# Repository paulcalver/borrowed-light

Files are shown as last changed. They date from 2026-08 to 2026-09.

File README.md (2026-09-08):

# Borrowed Light

*Global Colour: a live network reading the colour of daylight around the world.*

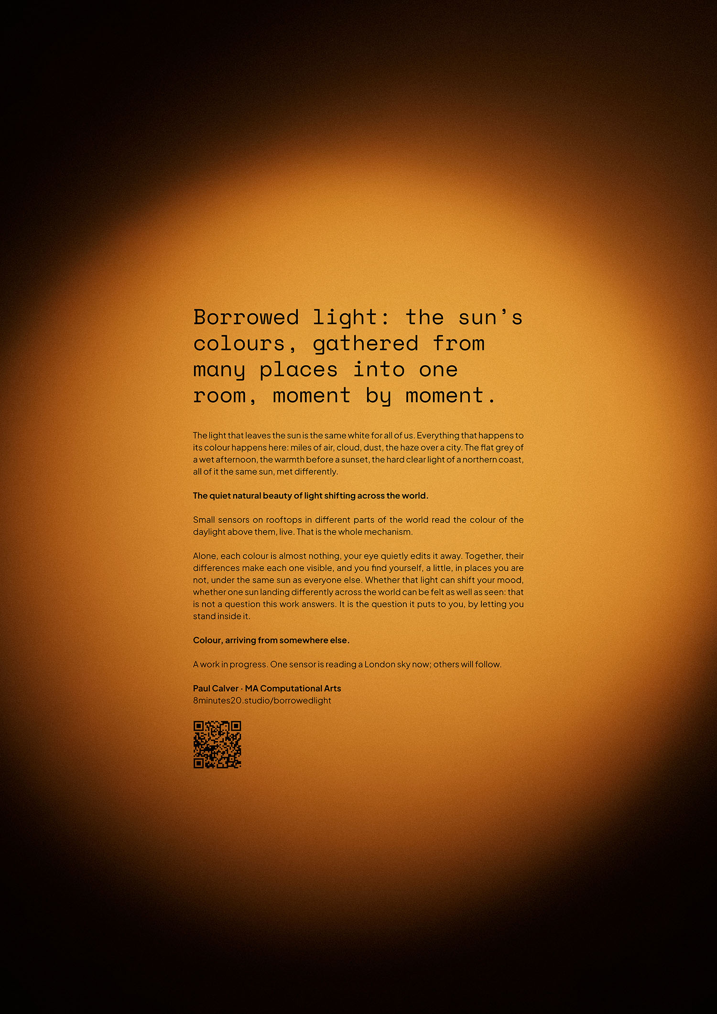
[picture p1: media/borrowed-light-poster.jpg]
Borrowed Light — the sun's colours, gathered from many places into one room, moment by moment. Small sensors on rooftops in different parts of the world read the colour of the daylight above them.


**Borrowed light: the sun's colours, gathered from many places into one room, moment by moment.**

The light that leaves the sun is the same white for all of us. Everything that happens to its colour happens here: miles of air, cloud, dust, the haze over a city. The flat grey of a wet afternoon, the warmth before a sunset, the hard clear light of a northern coast, all of it the same sun, met differently.

*The quiet natural beauty of light shifting across the world.*

Small sensors on rooftops in different parts of the world read the colour of the daylight above them, live. That is the whole mechanism.

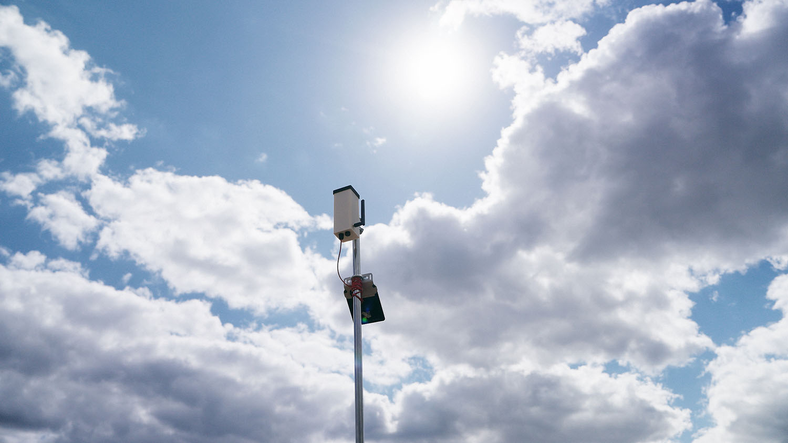
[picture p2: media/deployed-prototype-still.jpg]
A sensor unit mounted at the top of a pole, seen from below against bright sky — the enclosure with its dome facing up, solar panel angled beneath it, sun and cumulus cloud behind.


*A prototype unit in place, dome to the sky.*

Alone, each colour is almost nothing, your eye quietly edits it away. Together, their differences make each one visible, and you find yourself, a little, in places you are not, under the same sun as everyone else. Whether that light can shift your mood, whether one sun landing differently across the world can be felt as well as seen: that is not a question this work answers. It is the question it puts to you, by letting you stand inside it.

*Colour, arriving from somewhere else.*

A work in progress, and openly so. One sensor has been reading a London sky; others will follow, elsewhere. What form the standing-inside finally takes, whether light, projection, or something else, is still being explored.

**[8minutes20.studio/borrowedlight](https://8minutes20.studio/borrowedlight)**

If you would like to hear more about the project's plans and ambitions, please do get in touch.

---

## In plain terms

Hold an identical piece of white paper under the sun in different places and it looks a subtly different colour, not because the paper changes, but because the light falling on it does. The eye compensates for this automatically and mostly hides it; the sensor does not, and records the daylight's actual colour instead. The long-term aim is a distributed network of these sensors, one per site (London first, then elsewhere), each feeding the same live dashboard, so that difference becomes something you can see and compare directly.

## Status

Three units exist. `sensor-00` is the bench reference: it stays indoors permanently and is never deployed, so every future unit can be checked against it rather than against a borrowed meter each time. `sensor-01` is the London unit. `sensor-02` will go somewhere else once there is a site for it.

**None of them is in a final position yet.** The units are being rebuilt around new optics, described below, and are running on the bench while that happens. Siting, and a full recalibration once the new stack is fixed, both come after. The photographs here show prototypes in place, not the finished network.

### The dome problem, and its fix

Field readings through the summer of 2026 showed a colour-temperature error that tracked ambient UV rather than the light being measured: on the first outdoor comparison against a reference meter, all three units read between 900K and 1,160K too high, consistently, within seconds of each other. Duv barely moved, which is the signature of added blue light rather than a mis-aimed sensor or a bad fit.

The cause was optical brighteners fluorescing under sunlight — the material absorbs ultraviolet and re-emits it as visible blue, straight into the sensor. A 365nm test in August 2026 confirmed the source: the dome glowed strongly, the printed mixing tube behind it only slightly. Studio calibration had been structurally blind to this, because the lamp used for it emits almost no UV. The error only ever appeared in real sun.

It could not be fitted out afterwards, for reasons covered under [Calibration: physical](#calibration-physical) below. The fix had to be a material change, and that is now resolved. **LIT Systems**, who make the Lit Duo 1 spectrometer, supplied dome diffusers, UV/IR cutoff filters and black foam mounting rings from their own instrument — known-good parts from a working commercial colour meter rather than another material of unknown provenance. All of them pass the 365nm test. Domes were chosen over the flat diffusers deliberately, to keep the warmth of low sun in the readings rather than have it cosine-weighted away.

The enclosure has been reworked around them, and the printed mixing chamber is gone entirely: the foam ring mounts the filter directly over the OPT4048 and the dome sits close above it, so the light path is dome, filter, sensor, with no white plastic in it anywhere. That second change is not only about fluorescence — white ASA yellows over time, a slow, invisible spectral drift that would quietly invalidate any calibration fit. The files in [`mechanical/`](mechanical/) are this revision.

## Technical notes

Adafruit QT Py ESP32-S2, OPT4048 tristimulus colour sensor, Voltaic P126 solar panel (6V, 2W), 2000 mAh LiPo battery, BQ24074 charge controller, MQTT over Wi-Fi, custom 3D-printed enclosure. On-device loop: read CIE x,y chromaticity and lux, publish over MQTT. Server: convert to kelvin, render true colour from the raw measurement. Each unit is designed and hand-built, running on solar power alone with no mains connection. The sensor measures the light itself, not the sky's appearance.

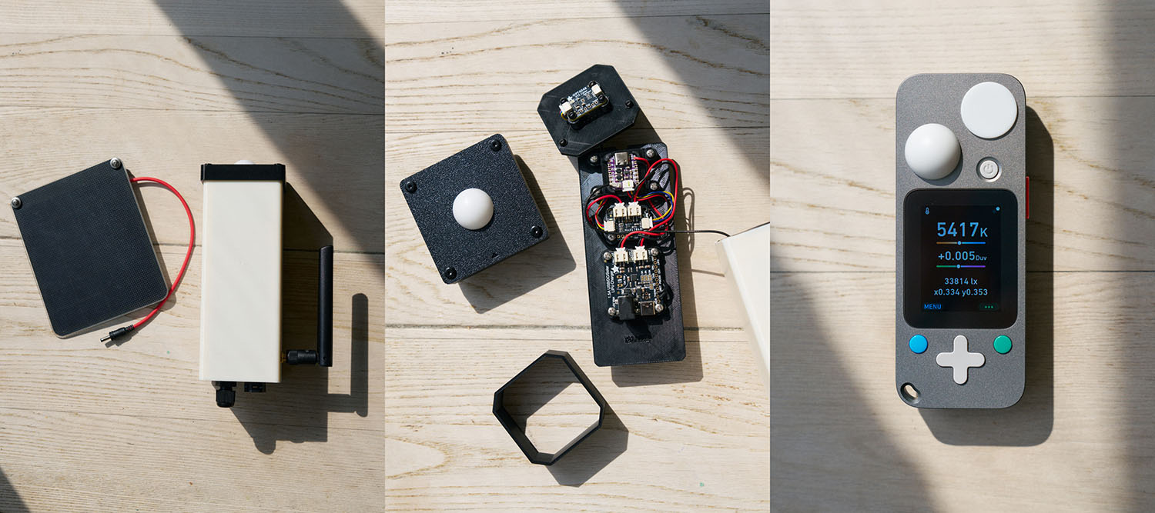
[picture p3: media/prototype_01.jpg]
Three views of a sensor unit: the assembled enclosure beside its solar panel, the same unit opened out to show the dome, the stacked boards and the battery sled, and the handheld reference colour meter reading 5417K at +0.005 Duv.


*Left: an assembled unit with its solar panel. Centre: the same unit opened out — dome and clamp ring, sensor deck, and the sled carrying the microcontroller, fuel gauge and charge controller. Right: the reference colour meter the units are calibrated against. This is the earlier flanged-dome build; the clamp ring and mixing tube are gone in the current revision.*

The rest of this page is the long version of that summary.

---

## How it works

Sensor to `hex`: what each reading goes through, and how separate units are checked against each other and against a physical reference.

### Sensor

An `OPT4048` tristimulus colour sensor sits behind the dome and diffuser, reading four raw channels (`X`, `Y`, `Z`, and a clear `W` channel) once per publish cycle. Unlike an RGB camera sensor, these four channels are built to match the CIE 1931 colour-matching functions directly, so colour and level convert straight to standard colorimetric quantities, CIE `x, y` chromaticity and lux, without a lookup table in between.

### On the device

The microcontroller reads the sensor, takes its `x, y` chromaticity, and derives correlated colour temperature (CCT): the temperature of the blackbody radiator whose colour is the nearest match on the CIE diagram. `cct`, `lux`, `cie_x`, `cie_y`, the raw channel counts, a sensor-overload flag, and battery state are packaged as JSON and published over MQTT to a self-hosted broker.

### On the server

CCT alone collapses a two-dimensional colour to a single number along the blackbody curve, discarding the axis perpendicular to it: whether the light sits slightly green or slightly magenta of a true blackbody at that temperature. The server recovers that as **Duv**, computed from the stored `x, y` using the CIE 1960 UCS transform and a closed-form fit to the Planckian locus (Ohno, 2011), accurate to a few parts in 10⁻⁴ across the daylight range. Each reading is also stamped with the sensor's registered location and the sun's elevation and azimuth at that instant, so a colour can be read against time of day and season, not just in isolation.

### Colour you see

The colour on the grid and full-screen views is the sensor's measured chromaticity rendered as true colour, not a Kelvin-to-RGB approximation. `x, y` is converted to CIE XYZ at unit luminance, then to linear sRGB with the standard D65 primary matrix. Out-of-gamut negative values are clipped, and the result is normalised so the brightest channel reads full strength, brightness being deliberately discarded here, so the display is a pure colour comparison rather than an exposure match. sRGB gamma is applied and the three channels are rounded to 8 bits, giving the `hex` value.

### Calibration: computational

The correction is built, but no sensor has been fitted yet, so every CCT, `x, y`, and Duv value shown is still the sensor's raw reading. It is a small per-unit affine adjustment in mireds (10⁶/K, the scale colour-temperature error behaves linearly on) and Duv, fitted once against a trusted physical reference and then applied at ingest, the same stage Duv is already computed at. Raw values are never overwritten: the calibrated columns sit alongside them and stay empty until a fit exists, so a fit can be refined or redone as more reference data comes in without losing anything.

### Calibration: physical

That reference comes from a direct bench comparison. Two identically built units, same dome, diffuser, and sensor, are run side by side against a borrowed professional colour meter before either goes outdoors. Once the fit is established:

- one unit deploys to its site,
- the other stays permanently on the bench as a fixed source of truth, and
- every future unit gets checked against that bench reference, rather than against the meter each time.

The reference unit is never itself installed outdoors, so its own drift stays out of the loop.

This is also the limit the dome problem ran into. An affine fit can absorb a bias that is stable, or one that varies with colour temperature itself, because both are recoverable from the reading. It cannot absorb one driven by ambient UV, which varies independently of the colour being measured, and that is why the fix had to be a material change rather than a better fit.

---

## This repository

    firmware/     CircuitPython for the QT Py ESP32-S2. Reads the OPT4048,
                  derives CCT on-device, publishes over MQTT. Multi-SSID
                  fallback, NTP-aligned capture, optional OTA pull.
    mechanical/   STEP exports of the IP65 enclosure and its pole and
                  wall-mount brackets, built around the LIT Systems dome.
                  Generated from a parametric model, so geometry is derived
                  rather than drawn: change a component and the box follows.
    server/       Ingests MQTT, computes Duv and solar position, stores
                  readings, and serves the true-colour views.

Host addresses in `firmware/qt-py/settings.toml.example` are placeholders. Set `MQTT_BROKER`, `MQTT_USERNAME`, `MQTT_PASSWORD` and, if you want over-the-air updates, `OTA_BASE_URL` for your own deployment.

A full build guide — bill of materials, wiring, assembly, print settings — is still to come.

## Contact

**Paul Calver** — [paulcalver@me.com](mailto:paulcalver@me.com)

Project page: [8minutes20.studio/borrowedlight](https://8minutes20.studio/borrowedlight)

Do get in touch about putting a sensor on a roof somewhere the network does not
yet reach, or about the project generally.

## Licence

MIT, see [LICENSE](LICENSE). The CircuitPython libraries under `firmware/qt-py/lib/` are redistributed from the Adafruit bundle and keep their own MIT copyright.

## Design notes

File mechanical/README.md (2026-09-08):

# Enclosure

STEP exports of the IP65 sensor enclosure, in millimetres. These are the
published geometry: the parts are generated from a parametric CadQuery model,
and what is exported here is what gets printed.

This is the current revision, built around the LIT Systems dome diffuser — the
UV-stable, brightener-free optic that replaced the earlier fluorescing dome. It
supersedes the flanged-dome enclosure the first prototypes used.

    assembly/
      column_assembly.step    The whole unit as it goes together, including
                              reference bodies for the dome, filter, foam ring,
                              boards and battery — for context and fit-checking,
                              not for printing.

    components/
      box.step                Open-top cup, 66 mm square, 171 mm deep. PG7
                              gland and breather vent in the bottom face;
                              moulded ledges carry the sensor deck, guide
                              fences locate the sled.
      lid.step                Screw-down lid, and the optical head. The dome
                              presses into a 20.5 mm port bore from outside and
                              beds in neutral-cure silicone; a rotation lock
                              catches one of the dome's barrel slots. Everything
                              optical stays with the lid when it lifts off.
      sensor_deck.step        Sits on the box's wall ledges and carries a riser
                              that lifts the OPT4048 up to meet the dome, die up
                              on the dome axis. Riser height is the tuning knob
                              for foam compression — reprint the deck alone to
                              adjust it.
      sled.step               Carries the QT Py, fuel gauge and charge
                              controller, and slides out of the box as one
                              piece.
      battery_cradle.step     Holds the 2000 mAh LiPo against the sled.
      pole_bracket.step       Friction clamp for a pole, dovetailed to the box.
      wall_mount_bracket.step Screws to a flat surface, same dovetail.

## Orientation

TOP is the end carrying the dome port and the screw-down lid; deployed, it faces
the sky. BOTTOM carries the gland and vent and points down, so water drains away
from both.

## Printing

Printed in ASA for UV stability, lid exterior-face down. No white plastic
anywhere in the light path: white ASA yellows over time, which would quietly
drift a calibration fit out from under you.

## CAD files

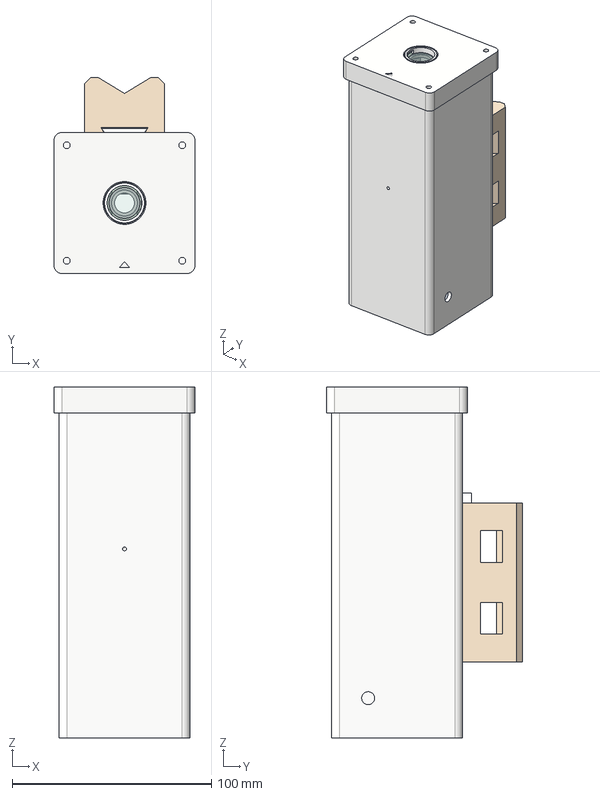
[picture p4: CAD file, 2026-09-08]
mechanical/assembly/column_assembly.step
70.8 x 98.4 x 176.3 mm
box_part
lid_part
deck_part
sled_part
battery_cradle_part
bracket_part
dome_part
ref_uv_ir_filter_part
ref_foam_ring_part
refs_boards_battery_part
ref_opt4048_part

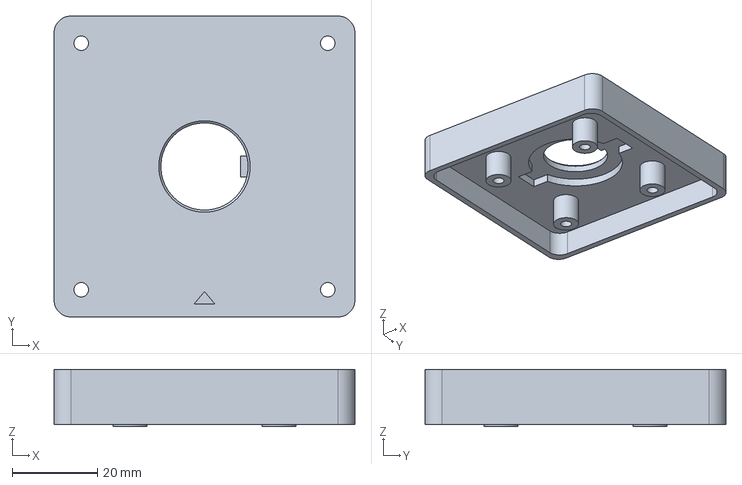
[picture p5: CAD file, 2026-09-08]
mechanical/components/lid.step
70.8 x 70.8 x 13.5 mm

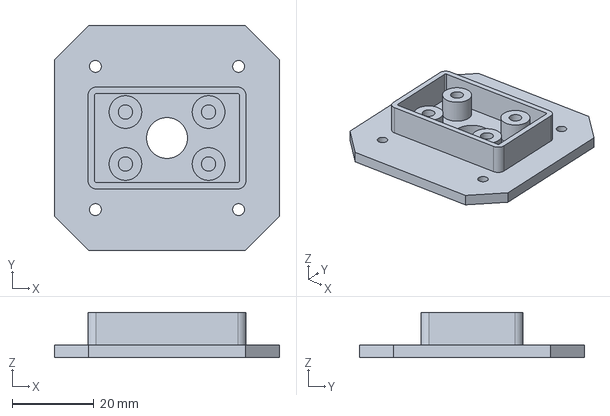
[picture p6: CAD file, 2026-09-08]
mechanical/components/sensor_deck.step
55.0 x 55.0 x 11.0 mm

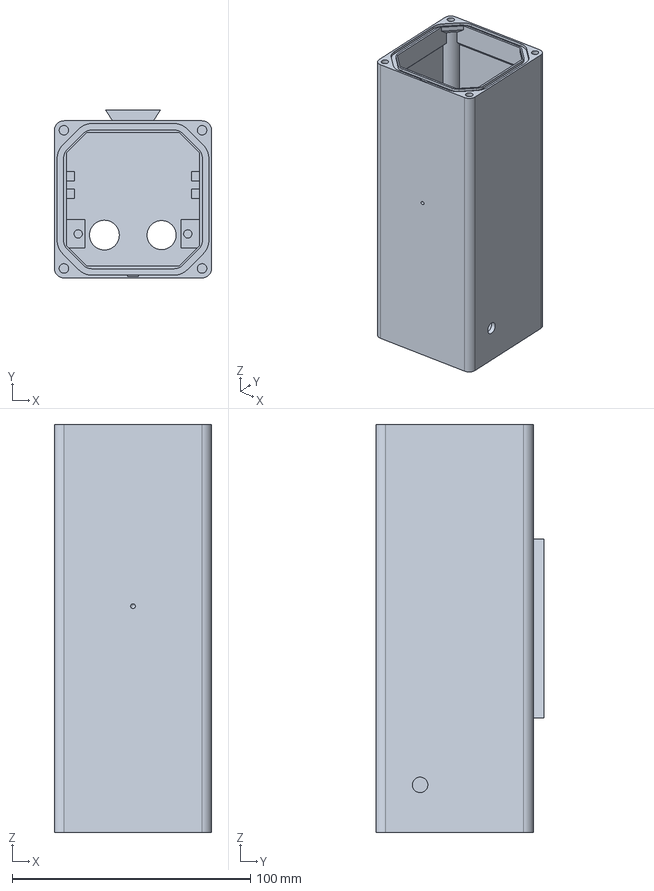
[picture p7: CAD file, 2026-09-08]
mechanical/components/box.step
66.0 x 70.5 x 171.3 mm

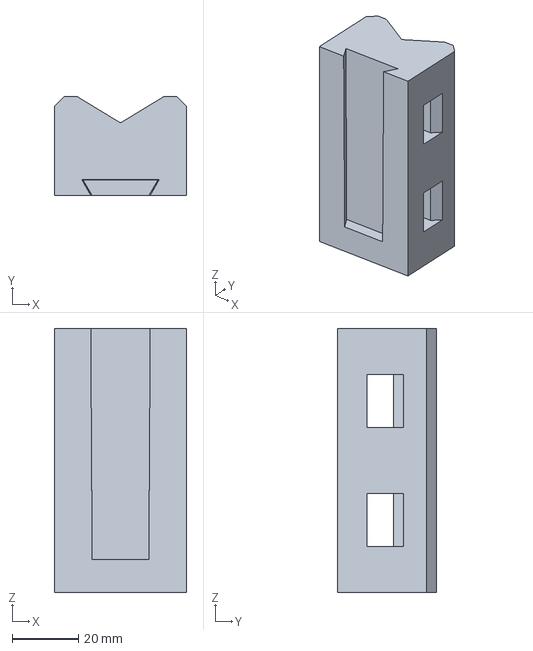
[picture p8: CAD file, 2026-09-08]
mechanical/components/pole_bracket.step
40.0 x 30.0 x 80.0 mm

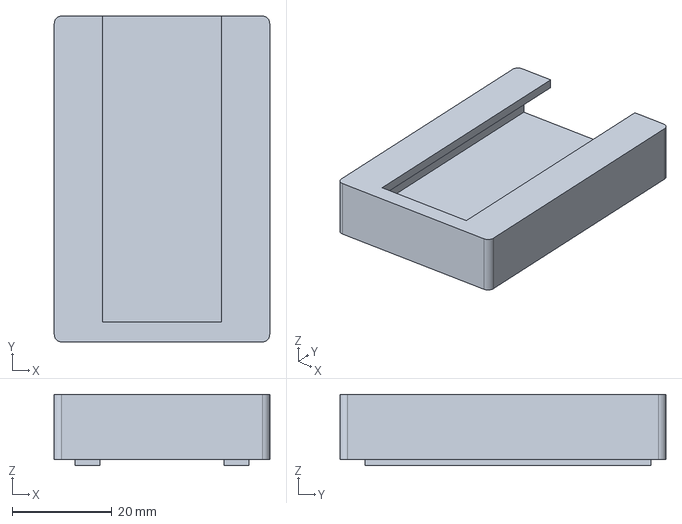
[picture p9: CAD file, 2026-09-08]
mechanical/components/battery_cradle.step
43.3 x 65.5 x 14.3 mm

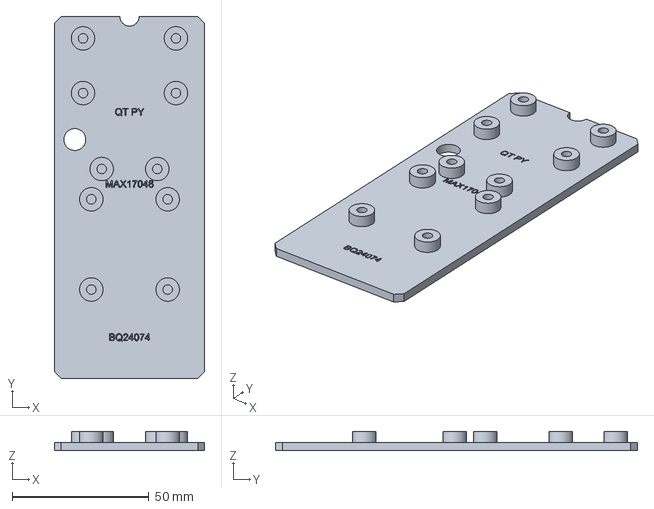
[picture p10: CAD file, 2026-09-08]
mechanical/components/sled.step
55.0 x 132.4 x 7.00 mm

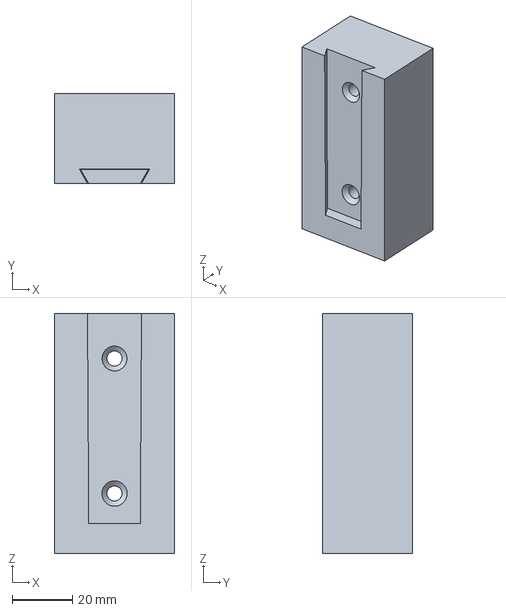
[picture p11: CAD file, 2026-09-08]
mechanical/components/wall_mount_bracket.step
40.0 x 30.0 x 80.0 mm

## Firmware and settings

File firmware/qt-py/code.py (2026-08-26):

"""
OPT4048 + MAX17048 -> MQTT publisher (own broker, not Adafruit IO)

Publishes CCT, lux, CIE x/y, and battery state as a single JSON payload
over MQTT to a self-hosted Mosquitto broker on DigitalOcean.

Battery temperature safety (Stage 1): a 10k NTC thermistor is wired to the
BQ24074 THERM pin. The charger uses it autonomously to throttle/cut charging
on a hot battery -- the MCU never reads it, so no temperature value appears in
the payload. Loggable temperature is a future Stage 3 job (a *second*,
independent NTC divider into GPIO2/A2); it does not touch the BQ24074.

Hardened for unattended operation: a single network/sensor error never
kills the loop, the connection is re-established automatically, and a
hardware watchdog reboots the board if it ever truly hangs.
"""

import time
import json
import os
import wifi
import socketpool
import board
import digitalio
import microcontroller
import alarm
from watchdog import WatchDogMode
import adafruit_opt4048
from adafruit_opt4048 import Mode, Range
from adafruit_max1704x import MAX17048
import adafruit_minimqtt.adafruit_minimqtt as MQTT

PUBLISH_INTERVAL = 120      # seconds between daytime readings (CALIBRATION: 2min so there's time to walk between sensors/read the meter/enter values; was 30s, revert to 300 for production)
WATCHDOG_TIMEOUT = 90       # board resets if the loop stalls longer than this
WATCHDOG_SLEEP_CHUNK = 10   # feed the watchdog this often while idling between readings
MAX_FAILURES = 5            # consecutive errors before a clean reboot

# --- Synchronised capture ---
# Two units left free-running drift apart by up to a full PUBLISH_INTERVAL,
# depending only on when each happened to boot, which makes side-by-side
# calibration readings hard to pair up. Instead each unit sleeps until the next
# PUBLISH_INTERVAL boundary on the *wall clock*, so every unit captures on the
# same absolute grid (e.g. at :00, :02, :04 past the hour at 120 s) regardless
# of boot time, and re-aligns itself after any reboot or network stall.
# Requires adafruit_ntp.mpy in lib/; without it the board free-runs as before.
SYNC_CAPTURES = True
NTP_HOST = "pool.ntp.org"
NTP_CACHE_SECONDS = 3600    # re-query NTP at most hourly; interpolate in between

# Night power saving. Below NIGHT_LUX_FLOOR the light sits at the sensor's noise
# floor and the colour data is useless (the chromaticity is pure noise), so the
# board deep-sleeps with the radio off. That is the only change that gives an
# order-of-magnitude battery saving; trimming idle draw while connected does
# not, because the always-on radio dominates. The board still wakes every
# NIGHT_INTERVAL for a battery/lux heartbeat (which keeps the overnight
# discharge curve and a grey night band on the grid), and stays connected for
# NIGHT_AWAKE_GRACE seconds around that heartbeat so wireless flashing remains
# catchable at night. Detection is purely from measured lux, so it needs no
# clock, location, or NTP, and it self-adjusts to season and weather.
NIGHT_LUX_FLOOR = 0.1       # lux; below this a reading is treated as true night
NIGHT_INTERVAL = 900        # seconds of deep sleep between night heartbeats (15 min, to catch dawn)
NIGHT_AWAKE_GRACE = 20      # seconds to stay connected around a night heartbeat (for flashing)
SENSOR_ID = os.getenv("SENSOR_ID", "sensor-01")
TOPIC = f"cct-sensor/{SENSOR_ID}/readings"

# --- Over-the-air (OTA) firmware ---
# The board PULLS new code.py from the Droplet, so flashing works from anywhere
# (not just the home LAN): the board makes the outbound HTTPS call, so no port
# forward, VPN, or inbound access to the home network is needed. On each check
# it reads a tiny manifest and downloads only when the server's version is
# newer than the one it last applied. Set OTA_BASE_URL in settings.toml to
# enable it (e.g. "https://your-server.example.com/firmware"); leave it unset to
# disable OTA entirely. OTA_TOKEN is optional and only needed if the server
# sets one. Wireless LAN flashing still works as before, and stays the fast
# path when you are at home.
OTA_BASE_URL = os.getenv("OTA_BASE_URL")
OTA_TOKEN = os.getenv("OTA_TOKEN")
OTA_CHECK_INTERVAL = 900     # seconds between OTA checks while awake (day path)
OTA_VERSION_FILE = "ota_version"  # last-applied integer version, on the flash

# --- Watchdog ---
# If the loop ever blocks longer than WATCHDOG_TIMEOUT (e.g. a network call
# hangs forever), the chip resets itself instead of sitting dead. We "feed"
# it once per loop to say "still alive".
wdt = microcontroller.watchdog
wdt.mode = None  # stop if already running from a previous crash/auto-reload
wdt.timeout = WATCHDOG_TIMEOUT
wdt.mode = WatchDogMode.RESET

# --- Power saving (radio stays always-on; these trim idle draw) ---
# Both are wrapped so a wrong pin/attr name on a firmware update can never crash
# the boot and cost us the wireless-flash path.
#
# 1) Turn off the onboard RGB NeoPixel's power rail. It draws ~1-2 mA even when
#    idle and we never light it.
try:
    _neopixel_power = digitalio.DigitalInOut(board.NEOPIXEL_POWER)
    _neopixel_power.switch_to_output(value=False)
    print("NeoPixel power rail off.")
except Exception as e:
    print("NeoPixel power-off skipped:", e)

# 2) Most aggressive Wi-Fi modem sleep. MIN (modem sleep between the AP's DTIM
#    beacons) is the default; MAX wakes the radio less often for a bit more
#    saving. Fine here: we only publish every few minutes and never rely on
#    low-latency downlink, and the keep-alive is far longer than the interval.
try:
    wifi.radio.power_management = wifi.PowerManagement.MAX
    print("Wi-Fi power management: MAX.")
except Exception as e:
    print("Wi-Fi power_management set skipped:", e)

# --- Sensor setup ---
i2c = board.STEMMA_I2C()
opt4048 = adafruit_opt4048.OPT4048(i2c)
opt4048.mode = Mode.CONTINUOUS
opt4048.range = Range.AUTO
try:
    max17048 = MAX17048(i2c)
    # No quick_start on boot: the MAX17048 is powered from the cell, so it keeps
    # its learned ModelGauge state across MCU reboots. quick_start would discard
    # that and re-guess from instantaneous voltage, which reads high when USB/
    # charger is present. Only quick_start once, manually, on fresh battery swap.
    print("MAX17048 found.")
except Exception as e:
    max17048 = None
    print("MAX17048 not found (battery hardware not connected):", e)
print(f"Sensors configured. Sensor ID: {SENSOR_ID}")
time.sleep(0.5)  # let the first OPT4048 conversion complete

# --- Networking ---
pool = socketpool.SocketPool(wifi.radio)

# HTTPS session for OTA. Built defensively: if adafruit_requests/ssl are missing
# from lib/ (they are separate from the MQTT stack), OTA simply stays disabled
# rather than crashing the boot and costing us the wireless-flash path. Requires
# adafruit_requests.mpy in lib/ (adafruit_connection_manager is already there).
_ota_requests = None
if OTA_BASE_URL:
    try:
        import ssl
        import adafruit_requests
        _ota_requests = adafruit_requests.Session(pool, ssl.create_default_context())
        print("OTA enabled:", OTA_BASE_URL)
    except Exception as e:
        print("OTA disabled (requests/ssl unavailable):", e)

# Wall clock for synchronised capture. Built defensively, exactly like the OTA
# session above: if adafruit_ntp.mpy is missing from lib/ the board simply
# free-runs instead of crashing the boot and costing us the flash path. No
# network call happens here -- adafruit_ntp queries lazily on first use.
_ntp = None
if SYNC_CAPTURES:
    try:
        import adafruit_ntp
        _ntp = adafruit_ntp.NTP(pool, server=NTP_HOST, tz_offset=0,
                                cache_seconds=NTP_CACHE_SECONDS)
        print("Capture sync enabled via", NTP_HOST)
    except Exception as e:
        print("Capture sync disabled (adafruit_ntp unavailable):", e)

mqtt_client = MQTT.MQTT(
    broker=os.getenv("MQTT_BROKER"),       # e.g. "broker.example.com"
    port=1883,
    username=os.getenv("MQTT_USERNAME"),   # e.g. "feather"
    password=os.getenv("MQTT_PASSWORD"),
    socket_pool=pool,
    keep_alive=max(60, PUBLISH_INTERVAL * 3),  # floor at 60s so a short interval cannot thrash MQTT
)


def _wifi_networks():
    """Every configured network, in the order they should be tried.

    CIRCUITPY_WIFI_SSID stays the primary because CircuitPython's own web
    workflow auto-connects to that one at boot, before code.py runs. The
    numbered pairs (CIRCUITPY_WIFI_SSID_2, _3, ...) are fallbacks used only by
    this loop, so a unit can follow a phone hotspot without losing the home
    network. Unset entries are skipped, so one network alone behaves as before.
    """
    nets = []
    for suffix in ("", "_2", "_3"):
        ssid = os.getenv("CIRCUITPY_WIFI_SSID" + suffix)
        if ssid:
            nets.append((ssid, os.getenv("CIRCUITPY_WIFI_PASSWORD" + suffix)))
    return nets


def connect():
    """(Re)establish Wi-Fi and MQTT. Raises if it can't — the caller handles it."""
    if not wifi.radio.connected:
        # Try each network in turn and keep the last error, so a total failure
        # still raises something meaningful for the caller's retry/reset logic.
        last_error = None
        for ssid, password in _wifi_networks():
            try:
                print("Connecting to Wi-Fi:", ssid)
                wifi.radio.connect(ssid, password)
                break
            except Exception as e:
                print("Wi-Fi failed on", ssid, "--", e)
                last_error = e
        if not wifi.radio.connected:
            raise last_error or RuntimeError("No Wi-Fi networks configured")
        print("Wi-Fi connected:", wifi.radio.ipv4_address)
    # Idempotent: only (re)connect MQTT if it is not already up. At the fast
    # daytime cadence, calling connect() every loop would otherwise open a new
    # connection every second (a reconnect storm). is_connected() raises rather
    # than returns False in some versions, so treat any error as "not connected".
    try:
        already_connected = mqtt_client.is_connected()
    except Exception:
        already_connected = False
    if not already_connected:
        print("Connecting to MQTT broker...")
        mqtt_client.connect()
        print("Connected to broker.")


def _ota_local_version():
    """The firmware version currently installed (0 if never OTA'd)."""
    try:
        with open(OTA_VERSION_FILE) as f:
            return int(f.read().strip())
    except (OSError, ValueError):
        return 0


def _ota_url(name):
    url = OTA_BASE_URL.rstrip("/") + "/" + name
    if OTA_TOKEN:
        url += "?token=" + OTA_TOKEN
    return url


def check_and_apply_ota():
    """Pull newer firmware from the Droplet and self-install. Never raises.

    Flow: read the manifest, and if its version is newer than what we last
    applied, download code.py, verify its byte length matches the manifest
    (so a truncated download is rejected, not installed), write it via a temp
    file + atomic rename, record the new version, and reload. Because this runs
    early each awake cycle, a later bug in a freshly installed code.py can still
    be healed by pushing another update -- as long as Wi-Fi still comes up.
    """
    if _ota_requests is None:
        return
    try:
        r = _ota_requests.get(_ota_url("manifest.json"), timeout=20)
        manifest = r.json()
        r.close()
    except Exception as e:
        print("OTA: manifest check failed:", e)
        return

    remote_v = int(manifest.get("version", 0))
    if remote_v <= _ota_local_version():
        return  # already up to date

    print(f"OTA: version {remote_v} available (have {_ota_local_version()}); downloading.")
    try:
        r = _ota_requests.get(_ota_url("code.py"), timeout=60)
        source = r.content  # bytes
        r.close()
    except Exception as e:
        print("OTA: download failed:", e)
        return

    expected = manifest.get("size")
    if expected is not None and len(source) != expected:
        print(f"OTA: size mismatch (got {len(source)}, expected {expected}); aborting.")
        return

    try:
        # Stage to a temp file first (size already verified above), then swap it
        # in. FAT's rename won't overwrite an existing file, so remove the old
        # code.py first. The gap is tiny; if power is lost inside it, recover
        # over USB — code.py.new holds the complete new firmware.
        with open("code.py.new", "wb") as f:
            f.write(source)
        try:
            os.remove("code.py")
        except OSError:
            pass
        os.rename("code.py.new", "code.py")
        with open(OTA_VERSION_FILE, "w") as f:
            f.write(str(remote_v))
    except Exception as e:
        print("OTA: install failed (filesystem not writable? see boot.py):", e)
        return

    print(f"OTA: installed version {remote_v}; reloading.")
    import supervisor
    supervisor.reload()  # never returns: re-runs the new code.py from the top


OVERLOAD_FLAG = 0x08  # bit 3 of opt4048.flags == sensor saturated


def read_diagnostics():
    """Return raw-channel diagnostics as a dict, or {} on a sensor read error.

    - overload True  -> the sensor is saturated; the reading is unreliable.
    - low zx_ratio   -> little blue (Z) relative to red (X), e.g. window glass
      cutting blue, which warms the CCT.
    """
    try:
        x_ch, y_ch, z_ch, w_ch = opt4048.all_channels  # raw ADC counts
        flags = opt4048.flags
        return {
            "raw_x": x_ch,
            "raw_y": y_ch,
            "raw_z": z_ch,
            "raw_w": w_ch,
            "zx_ratio": round(z_ch / x_ch, 3) if x_ch else 0,
            "overload": bool(flags & OVERLOAD_FLAG),
        }
    except Exception as e:
        print("  diag read failed:", e)
        return {}


def read_battery():
    """Return battery voltage and SoC% from MAX17048, or {} on error.

    Temperature is handled autonomously by the BQ24074 via its THERM pin
    and is not read by the MCU in this configuration.
    """
    if max17048 is None:
        return {}
    try:
        return {
            "battery_v": round(max17048.cell_voltage, 3),
            "battery_pct": round(min(max17048.cell_percent, 100.0), 1),
        }
    except Exception as e:
        print("  battery read failed:", e)
        return {}


def read_and_publish(cie_x, cie_y, lux):
    """Publish one reading from already-read sensor values.

    The caller reads opt4048.cie once (radio off) to make the day/night
    decision and passes the values here, so the sensor is not read twice. May
    raise on a network error.
    """
    cct = opt4048.calculate_color_temperature(cie_x, cie_y)
    payload = {
        "sensor_id": SENSOR_ID,
        "cct": round(cct, 1),
        "lux": round(lux, 2),
        "cie_x": round(cie_x, 4),
        "cie_y": round(cie_y, 4),
    }
    payload.update(read_battery())      # adds battery_v, battery_pct
    payload.update(read_diagnostics())  # adds raw_x/y/z/w, zx_ratio, overload
    payload_json = json.dumps(payload)
    print(payload_json)
    mqtt_client.publish(TOPIC, payload_json)


def idle(seconds):
    """Sleep for `seconds`, feeding the watchdog in short chunks.

    A single long time.sleep would let the 90s watchdog fire during the normal
    multi-minute gap between readings, so we sleep in WATCHDOG_SLEEP_CHUNK steps
    and feed the watchdog each step. A genuine mid-work hang still trips the
    watchdog; the long idle gap does not.
    """
    slept = 0
    while slept < seconds:
        chunk = min(WATCHDOG_SLEEP_CHUNK, seconds - slept)
        time.sleep(chunk)
        wdt.feed()
        slept += chunk


def seconds_to_next_capture():
    """Seconds to wait so the next reading lands on a wall-clock boundary.

    Alignment is done modulo the hour rather than against a Unix epoch, which
    avoids depending on time.mktime being present in the build. That is exact
    only when PUBLISH_INTERVAL divides an hour evenly (120 s does; 300 s does
    too), so anything else falls back to free-running rather than producing a
    jump at the top of each hour. Any NTP failure also falls back, so a network
    blip costs alignment for one cycle instead of stalling the loop.
    """
    if _ntp is None or 3600 % PUBLISH_INTERVAL:
        return PUBLISH_INTERVAL
    try:
        now = _ntp.datetime
    except Exception as e:
        print("NTP unavailable, free-running this cycle:", e)
        return PUBLISH_INTERVAL
    wait = PUBLISH_INTERVAL - ((now.tm_min * 60 + now.tm_sec) % PUBLISH_INTERVAL)
    # Landing exactly on a boundary would otherwise mean a ~0 s wait and two
    # readings in the same slot, so take the next slot instead.
    if wait < 1:
        wait += PUBLISH_INTERVAL
    return wait


def deep_sleep(seconds):
    """Power the radio down and deep-sleep for `seconds`, then reboot into code.py.

    Deep sleep is the only real battery saving on this board (the always-on
    radio otherwise dominates). We disable the watchdog first so its short
    timeout cannot reset us mid-sleep, and best-effort close the MQTT link
    (deep sleep drops the connection anyway). This never returns: the board
    resets and re-runs code.py (and boot.py) from the top on wake.
    """
    try:
        mqtt_client.disconnect()
    except Exception:
        pass
    wdt.mode = None  # a 90s watchdog must not fire during a multi-minute sleep
    time_alarm = alarm.time.TimeAlarm(monotonic_time=time.monotonic() + seconds)
    alarm.exit_and_deep_sleep_until_alarms(time_alarm)


# --- Main loop ---
# We do NOT connect at boot: read the light level first (radio off) so a boot
# that lands in the true-night window goes straight back to deep sleep without
# ever powering the radio. Everything is wrapped so no single error halts the
# program; the watchdog reboots the board if the loop ever truly hangs.
fail_count = 0
_last_ota_check = None   # monotonic time of the last OTA check; None = never
while True:
    wdt.feed()  # "still alive" — resets the watchdog countdown

    # Read the sensor once (no radio needed) for the day/night decision and the
    # values to publish. If the sensor read itself fails, wait and retry.
    try:
        cie_x, cie_y, lux = opt4048.cie
    except Exception as e:
        print("Sensor read failed:", e)
        idle(PUBLISH_INTERVAL)
        continue

    if lux < NIGHT_LUX_FLOOR:
        # NIGHT: colour data is noise. Send a best-effort battery/lux heartbeat,
        # linger briefly so wireless flashing stays catchable, then deep-sleep
        # the radio off until the next check. This is where the battery is saved.
        print(f"Night (lux {lux:.2f} < {NIGHT_LUX_FLOOR}): heartbeat, then deep sleep {NIGHT_INTERVAL}s.")
        try:
            connect()
            read_and_publish(cie_x, cie_y, lux)
        except Exception as e:
            print("Night heartbeat failed (sleeping anyway):", e)
        idle(NIGHT_AWAKE_GRACE)      # radio still up — a window to catch OTA flashing
        deep_sleep(NIGHT_INTERVAL)   # never returns; board reboots on wake

    # DAY: stay connected (always-on) so wireless flashing keeps working, and
    # publish at the normal cadence.
    target_wait = None    # seconds-to-boundary, captured before this cycle's
    work_start = None     # network work so that work's own duration (which
                           # differs per unit -- reconnects, hotspot latency,
                           # OTA checks) can't shift the shared wall-clock grid
    try:
        connect()
        # Capture the schedule target as soon as we're connected, *before* the
        # OTA check and publish below. Those take a variable amount of time
        # (longer on a unit that had to reconnect Wi-Fi, or one on a slower
        # hotspot fallback), and computing the target only after they finish
        # would bake that unit-specific delay into the grid as a fixed phase
        # offset -- each unit stays internally steady but drifts apart from
        # the others, which is exactly the "in sync with itself, not with the
        # others" symptom this was written to prevent.
        target_wait = seconds_to_next_capture()
        work_start = time.monotonic()
        # Check for new firmware early (radio is up) but at most every
        # OTA_CHECK_INTERVAL, so the fast daytime cadence never hammers it.
        # If an update installs, check_and_apply_ota() reloads and never returns.
        now_mono = time.monotonic()
        if _last_ota_check is None or now_mono - _last_ota_check >= OTA_CHECK_INTERVAL:
            _last_ota_check = now_mono
            check_and_apply_ota()
        read_and_publish(cie_x, cie_y, lux)
        fail_count = 0  # success: clear the failure streak
    except Exception as e:
        fail_count += 1
        print(f"Loop error ({fail_count}/{MAX_FAILURES}):", e)
        # Drop the (probably stale) connection and try to rebuild it.
        try:
            mqtt_client.disconnect()
        except Exception:
            pass
        try:
            connect()
        except Exception as e2:
            print("Reconnect failed:", e2)
        # If we keep failing, reboot for a guaranteed-clean slate.
        if fail_count >= MAX_FAILURES:
            print("Too many failures in a row — resetting board.")
            time.sleep(2)
            microcontroller.reset()

    # Sleep to the next wall-clock boundary rather than a flat interval, so
    # this unit stays in step with the others. Subtract whatever time this
    # cycle's work already used since target_wait was captured, so the actual
    # wake time lands on the boundary regardless of how long that work took.
    if target_wait is not None:
        elapsed = time.monotonic() - work_start
        idle(max(1, target_wait - elapsed))
    else:
        idle(seconds_to_next_capture())

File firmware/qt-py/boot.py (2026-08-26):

"""
Disable the CIRCUITPY USB mass-storage drive.

On native-USB boards (ESP32-S2/S3) the filesystem is reserved for USB MSC
unless this is disabled, which blocks writes from the web workflow (PUT to
/fs/... returns 500) even when no USB cable is attached. Disabling it here
is what makes WiFi flashing actually work. The USB serial/REPL console is
unaffected, so `screen /dev/tty.usbmodem...` still works as a fallback.
"""

import storage

storage.disable_usb_drive()

# Make the filesystem writable by CircuitPython itself, not just the web
# workflow. This is what lets code.py overwrite itself during an over-the-air
# update (see the OTA section in code.py). The web workflow and code.py share
# the same writable flag (USB is the only other claimant, and it is disabled
# above), so this does NOT break LAN wireless flashing -- both keep working.
# Wrapped so a remount failure can never halt boot and cost us the flash path.
try:
    storage.remount("/", readonly=False)
    print("Filesystem remounted read-write (OTA + web workflow can write).")
except Exception as e:
    print("Filesystem remount skipped:", e)

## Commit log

2026-08-26 Initial public release: firmware, enclosure CAD, and server
    Borrowed Light reads the colour of daylight from small rooftop sensors and
    renders it live. This is the finished code behind it.
    firmware/ CircuitPython for the QT Py ESP32-S2: OPT4048 tristimulus
    read, on-device CCT, MQTT publish, OTA pull, multi-SSID
    fallback and NTP-aligned capture.
    mechanical/ CadQuery source for the rev C IP65 enclosure, including the
    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
2026-08-26 Restore the full README narrative and technical walkthrough
    Reinstates the text from the previous repo: the project framing, the plain-terms
    explanation, fleet status, and the sensor-to-hex walkthrough covering the
    OPT4048 read, on-device CCT, server-side Duv, and true-colour rendering.
    Adds the show poster, a link to the project page, and a short guide to what is
    now in the repository, since the code has landed since this text was written.
    Corrects the computational-calibration section: it described the per-unit
    affine correction as planned, but it is implemented and shipped here. No sensor
    has been fitted yet, so the views still render raw readings.
2026-08-26 Lead with the dome fluorescence failure and the search for a supplier
    The offline status was buried mid-page. It now opens the README as a notice,
    with the full account promoted into Status: the size of the error, the 365nm
    test that identified the dome as the source, why studio calibration could not
    have caught it, and why no amount of reference data can correct it.
    States plainly that sourcing an OBA-free replacement diffuser is the open
    problem, that PTFE is the leading candidate but nothing is settled, and asks
    anyone who knows the material to get in touch.
2026-08-26 Add a contact section and wire the calls to action to it
    The README asked people to get in touch three times without giving them any
    way to do it. Adds an address and the project page at the foot, and points the
    offline notice and the supplier request at it.
2026-08-26 Add a build photo to the technical notes, restore the contact address
    Three views of a unit — assembled with its solar panel, opened out, and beside
    the reference meter — under the hardware summary, so the parts list has
    something to point at.
    Puts the email back in Contact: the address is already reachable from the
    project page, so withholding it here bought little and cost a reader the
    obvious way to make contact. Also adds some space above the poster.
2026-08-26 Add the deployed prototype still
    A unit in place against open sky, set against the line describing the
    mechanism, so the idea and the object appear together.
2026-08-26 Remove references to files that only exist in the private repo
    Comments pointed readers at CLAUDE.md, build-reference.md, publish_firmware.py,
    an adafruit-cad-files folder and a pole_mount_params.py, none of which are
    here — and the last of those no longer exists anywhere. Each pointer is
    replaced by the substance it was deferring to, or dropped where the
    surrounding text already said it.
    Comment-only; the enclosure script rebuilds with all assertions passing and
    identical geometry.
2026-09-08 Debug page: show sensor age in days/hours, not just minutes
    The status column counted minutes indefinitely, so a unit that had been
    quiet for a month read "47764m ago" -- a number you have to do arithmetic
    on before it means anything. formatAge() now steps the unit up as the age
    grows: seconds -> "just now", then minutes, then hours+minutes under a
    day, then days+hours under a week, then plain days.
    The second term is dropped once past a week, on the grounds that the
    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
2026-09-08 Publish the enclosure as STEP, and close out the dome problem
    The mechanical folder carried the CadQuery source for the old flanged-dome
    variant. Replace it with STEP exports of the current revision, built around
    the LIT Systems dome: box, lid, sensor deck, sled, battery cradle and both
    brackets, plus the full column assembly for context. STEP is what a reader
    can actually open and print; the parametric source stays private. Add a
    mechanical/README describing each part, and stop gitignoring *.step now
    that the exports are the deliverable.
    README: drop the offline banner and the search for a dome supplier. The
    material question is closed — LIT Systems supplied domes, UV/IR filters and
    foam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
    [battery_cradle.step, box.step, column_assembly.step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]
